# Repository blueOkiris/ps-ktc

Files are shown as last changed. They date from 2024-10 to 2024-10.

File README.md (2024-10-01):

# Polymath Studio Keyboard/Trackball Combo

NOTE: Project still in development!!!!

## Description

A keyboard and trackball in one, for efficient computer usage.

Like the [PS-OHK](https://github.com/blueOkiris/ps-ohk/), the PS-KTC attempts to provide an efficiently laid out keyboard which doesn't require moving your hands back and forth from the mouse.

Unlike the PS-OHK, it accomplishes this while allowing for typing quickly via using both hands. This is done by placing a trackball in the middle of the keyboard!

## Layout

Like the PS-OHK, the PS-KTC uses a custom keyboard layout designed around placing commonly used characters right on the home row followed by similar sounds being near each other. It also aims to be roughly a 100% keyboard, although a few shortcuts are taken.

Layout:

```
F1  F2  F3  F4  F5  F6                      F7  F8  F9  F10 F11 F12

                Hm  End                     PgU PgD

            3#                                      8*
        2@                                              9(
            F   4%                              7&  L
        D                                               U
Esc 1!      I   K   5%                      6^  P   R       0)
        T                                               O
Tab C       V   A   Y   LClk           RClk H   E   J       M
        X                                               W
Sft S       [{  G   ,<  Scrl                .>  B   ]}      N   `~
        ;:                Whl                          '"
CLk Z       \|  Ins BSp Del               -----     /?      Q
                                         /Track\
    =+  Up      Ctl Sp  Win             | Ball  |           -_   
                                         \     /    
    Lft Dwn Rt  Alt Ret Cmp               -----     
```

Where the home row is S, T, I, A, Space, Trackball, E, R, O, N

There are 82 keys here. Why not 100? Well, there are few reasons:

1. Due to the every key being available and close to a finger in this arrangement, there is no need for the 10 num-pad digits nor the Num Lock nor the num-pad duplicates of /, \*, -, +, Return, and \./Delete. That's 100 - 10 - 7 = 83
2. No Print Screen, Scroll Lock, or Pause because, let's be real, the vast majority of people, myself included, do not need these keys. Maybe Print Screen, but Super + Shift + S is a great key combo for screenshot, so Print Screen is not needed. That's 83 - 3 = 80 keys
3. Mouse clicks as keys. 82 (middle click = left + right)

## Cost

If you go with the recommended JLCPCB, Tindie, and Amazon links, the cost is roughly broken down like so

| Part | Cost (w/ shipping) |
|:---:|:---:|
| PCBs | $101.01 |
| Motion Sensor | $39.98 |
| Rotary Encoder  + Wires | $44.20 |
| Total | $185.19 |

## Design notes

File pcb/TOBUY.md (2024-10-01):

# Ordering

## PS-KTC PCBs

### Usb MCU

To build the USB/MCU board, you'll want to use the BOM/CPL in usb-mcu/ on JLCPCB.

### Keys

To build the IO-Expander board for connecting keys too, same as usb-mcu, but use the files in the keys/ folder

### Key(s)

You'll also need 82 of the key/ PCB. No assembly required.

## Other Things to Buy

### Motion Sensor

For the mouse motion sensing, grab a PMW3389 Motion Sensor like [this one](https://www.tindie.com/products/citizenjoe/pmw3389-motion-sensor/)

### Scroll Wheel

For the scroll wheel, grab [this rotary encoder](https://www.amazon.com/Cylewet-Encoder-Digital-Potentiometer-Arduino/dp/B07DM2YMT4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)

### Wires

You'll need a bunch of female to female jumper wires. Like 100 long ones and 100 short ones.

- [40x Long](https://www.amazon.com/Solderless-Multicolored-Electronic-Breadboard-Protoboard/dp/B09FP74HVH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)
- [40x Short](https://www.amazon.com/Solderless-Multicolored-Electronic-Breadboard-Protoboard/dp/B09FPL5QV8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)

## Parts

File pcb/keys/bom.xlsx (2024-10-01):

Comment | Designator | Footprint | Part #
PCA9505DGGY | IC_IOEXP2,IC_IOEXP1 | SOP50 P810X120-56N | C2669685

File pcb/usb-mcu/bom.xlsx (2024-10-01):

Comment | Designator | Footprint | Part #
CH552G | IC_MCU1 | SOP-16 | C111292
10k Ohm | R_I2C2,R_I2C1,R_PROG1 | 0603
100nF | C2,C1 | 0603
5.1k Ohm | R_CC2,R_CC1 | 0603
USB-C Con | J_USB1 | USB-C 16P | C2894898
6mm Push Button | SW_PROG1 |  | C255812

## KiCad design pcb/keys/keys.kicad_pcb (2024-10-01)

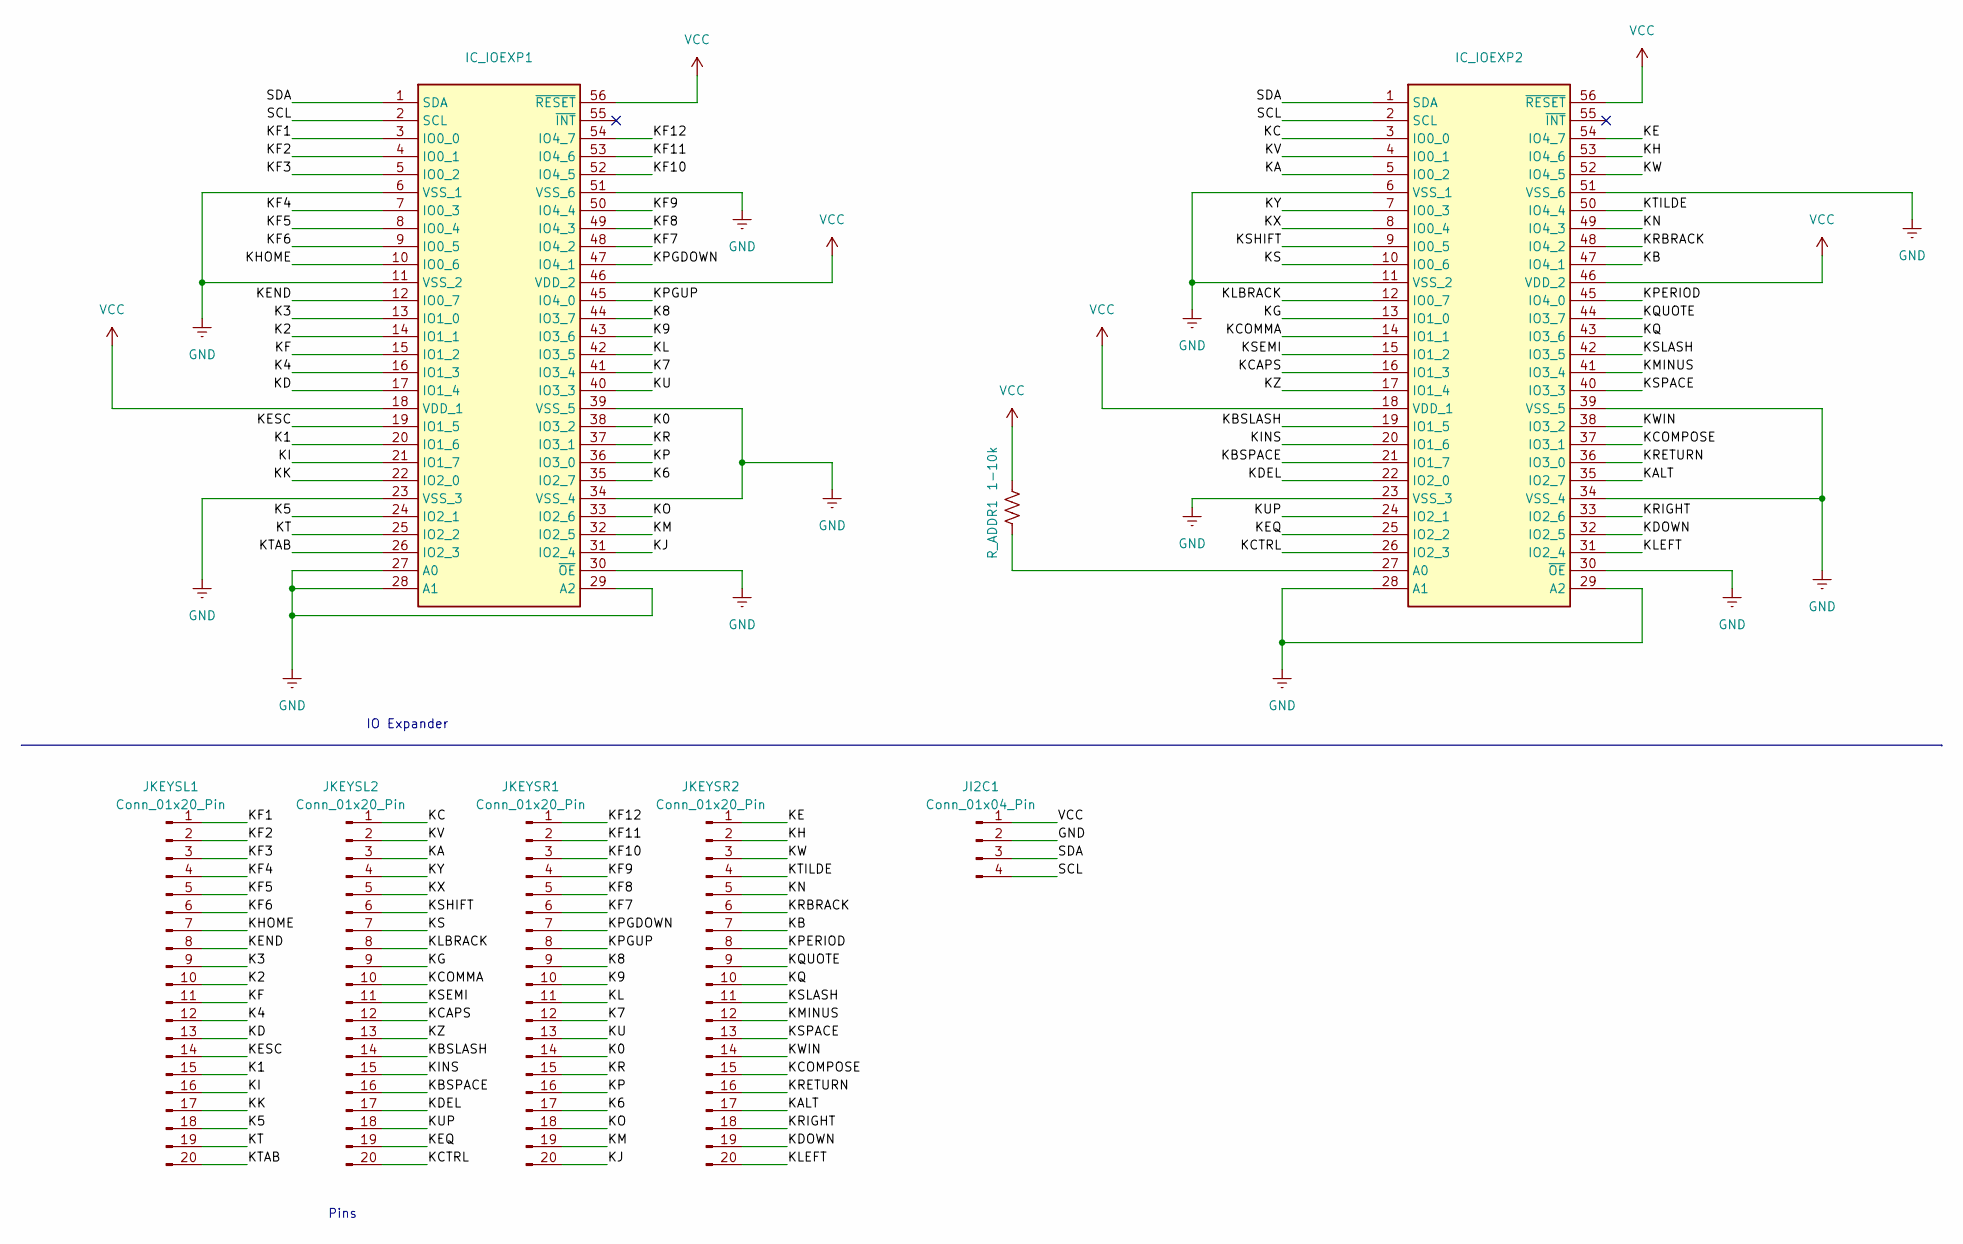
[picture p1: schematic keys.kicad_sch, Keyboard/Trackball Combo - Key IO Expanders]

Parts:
IC_IOEXP1, IC_IOEXP2: SOP50P810X120-56N; Mouser Part Number 771-PCA9505DGGY
JI2C1: Conn_01x04_Pin; PinHeader_1x04_P2.54mm_Vertical
JKEYSL1, JKEYSL2: Conn_01x20_Pin; PinHeader_1x20_P2.54mm_Vertical
JKEYSR1, JKEYSR2: Conn_01x20_Pin; PinHeader_1x20_P2.54mm_Vertical
R_ADDR1: 1-10k; R_0603_1608Metric

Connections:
/K0: IC_IOEXP1.38 (IO3_2), JKEYSR1.14
/K1: IC_IOEXP1.20 (IO1_6), JKEYSL1.15
/K2: IC_IOEXP1.14 (IO1_1), JKEYSL1.10
/K3: IC_IOEXP1.13 (IO1_0), JKEYSL1.9
/K4: IC_IOEXP1.16 (IO1_3), JKEYSL1.12
/K5: IC_IOEXP1.24 (IO2_1), JKEYSL1.18
/K6: IC_IOEXP1.35 (IO2_7), JKEYSR1.17
/K7: IC_IOEXP1.41 (IO3_4), JKEYSR1.12
/K8: IC_IOEXP1.44 (IO3_7), JKEYSR1.9
/K9: IC_IOEXP1.43 (IO3_6), JKEYSR1.10
/KA: IC_IOEXP2.5 (IO0_2), JKEYSL2.3
/KALT: IC_IOEXP2.35 (IO2_7), JKEYSR2.17
/KB: IC_IOEXP2.47 (IO4_1), JKEYSR2.7
/KBSLASH: IC_IOEXP2.19 (IO1_5), JKEYSL2.14
/KBSPACE: IC_IOEXP2.21 (IO1_7), JKEYSL2.16
/KC: IC_IOEXP2.3 (IO0_0), JKEYSL2.1
/KCAPS: IC_IOEXP2.16 (IO1_3), JKEYSL2.12
/KCOMMA: IC_IOEXP2.14 (IO1_1), JKEYSL2.10
/KCOMPOSE: IC_IOEXP2.37 (IO3_1), JKEYSR2.15
/KCTRL: IC_IOEXP2.26 (IO2_3), JKEYSL2.20
/KD: IC_IOEXP1.17 (IO1_4), JKEYSL1.13
/KDEL: IC_IOEXP2.22 (IO2_0), JKEYSL2.17
/KDOWN: IC_IOEXP2.32 (IO2_5), JKEYSR2.19
/KE: IC_IOEXP2.54 (IO4_7), JKEYSR2.1
/KEND: IC_IOEXP1.12 (IO0_7), JKEYSL1.8
/KEQ: IC_IOEXP2.25 (IO2_2), JKEYSL2.19
/KESC: IC_IOEXP1.19 (IO1_5), JKEYSL1.14
/KF: IC_IOEXP1.15 (IO1_2), JKEYSL1.11
/KF1: IC_IOEXP1.3 (IO0_0), JKEYSL1.1
/KF2: IC_IOEXP1.4 (IO0_1), JKEYSL1.2
/KF3: IC_IOEXP1.5 (IO0_2), JKEYSL1.3
/KF4: IC_IOEXP1.7 (IO0_3), JKEYSL1.4
/KF5: IC_IOEXP1.8 (IO0_4), JKEYSL1.5
/KF6: IC_IOEXP1.9 (IO0_5), JKEYSL1.6
/KF7: IC_IOEXP1.48 (IO4_2), JKEYSR1.6
/KF8: IC_IOEXP1.49 (IO4_3), JKEYSR1.5
/KF9: IC_IOEXP1.50 (IO4_4), JKEYSR1.4
/KF10: IC_IOEXP1.52 (IO4_5), JKEYSR1.3
/KF11: IC_IOEXP1.53 (IO4_6), JKEYSR1.2
/KF12: IC_IOEXP1.54 (IO4_7), JKEYSR1.1
/KG: IC_IOEXP2.13 (IO1_0), JKEYSL2.9
/KH: IC_IOEXP2.53 (IO4_6), JKEYSR2.2
/KHOME: IC_IOEXP1.10 (IO0_6), JKEYSL1.7
/KI: IC_IOEXP1.21 (IO1_7), JKEYSL1.16
/KINS: IC_IOEXP2.20 (IO1_6), JKEYSL2.15
/KJ: IC_IOEXP1.31 (IO2_4), JKEYSR1.20
/KK: IC_IOEXP1.22 (IO2_0), JKEYSL1.17
/KL: IC_IOEXP1.42 (IO3_5), JKEYSR1.11
/KLBRACK: IC_IOEXP2.12 (IO0_7), JKEYSL2.8
/KLEFT: IC_IOEXP2.31 (IO2_4), JKEYSR2.20
/KM: IC_IOEXP1.32 (IO2_5), JKEYSR1.19
/KMINUS: IC_IOEXP2.41 (IO3_4), JKEYSR2.12
/KN: IC_IOEXP2.49 (IO4_3), JKEYSR2.5
/KO: IC_IOEXP1.33 (IO2_6), JKEYSR1.18
/KP: IC_IOEXP1.36 (IO3_0), JKEYSR1.16
/KPERIOD: IC_IOEXP2.45 (IO4_0), JKEYSR2.8
/KPGDOWN: IC_IOEXP1.47 (IO4_1), JKEYSR1.7
/KPGUP: IC_IOEXP1.45 (IO4_0), JKEYSR1.8
/KQ: IC_IOEXP2.43 (IO3_6), JKEYSR2.10
/KQUOTE: IC_IOEXP2.44 (IO3_7), JKEYSR2.9
/KR: IC_IOEXP1.37 (IO3_1), JKEYSR1.15
/KRBRACK: IC_IOEXP2.48 (IO4_2), JKEYSR2.6
/KRETURN: IC_IOEXP2.36 (IO3_0), JKEYSR2.16
/KRIGHT: IC_IOEXP2.33 (IO2_6), JKEYSR2.18
/KS: IC_IOEXP2.10 (IO0_6), JKEYSL2.7
/KSEMI: IC_IOEXP2.15 (IO1_2), JKEYSL2.11
/KSHIFT: IC_IOEXP2.9 (IO0_5), JKEYSL2.6
/KSLASH: IC_IOEXP2.42 (IO3_5), JKEYSR2.11
/KSPACE: IC_IOEXP2.40 (IO3_3), JKEYSR2.13
/KT: IC_IOEXP1.25 (IO2_2), JKEYSL1.19
/KTAB: IC_IOEXP1.26 (IO2_3), JKEYSL1.20
/KTILDE: IC_IOEXP2.50 (IO4_4), JKEYSR2.4
/KU: IC_IOEXP1.40 (IO3_3), JKEYSR1.13
/KUP: IC_IOEXP2.24 (IO2_1), JKEYSL2.18
/KV: IC_IOEXP2.4 (IO0_1), JKEYSL2.2
/KW: IC_IOEXP2.52 (IO4_5), JKEYSR2.3
/KWIN: IC_IOEXP2.38 (IO3_2), JKEYSR2.14
/KX: IC_IOEXP2.8 (IO0_4), JKEYSL2.5
/KY: IC_IOEXP2.7 (IO0_3), JKEYSL2.4
/KZ: IC_IOEXP2.17 (IO1_4), JKEYSL2.13
/SCL: IC_IOEXP1.2 (SCL), IC_IOEXP2.2 (SCL), JI2C1.4
/SDA: IC_IOEXP1.1 (SDA), IC_IOEXP2.1 (SDA), JI2C1.3
GND: IC_IOEXP1.6 (VSS_1), IC_IOEXP1.11 (VSS_2), IC_IOEXP1.23 (VSS_3), IC_IOEXP1.27 (A0), IC_IOEXP1.28 (A1), IC_IOEXP1.29 (A2), IC_IOEXP1.30 (~OE), IC_IOEXP1.34 (VSS_4), IC_IOEXP1.39 (VSS_5), IC_IOEXP1.51 (VSS_6), IC_IOEXP2.6 (VSS_1), IC_IOEXP2.11 (VSS_2), IC_IOEXP2.23 (VSS_3), IC_IOEXP2.28 (A1), IC_IOEXP2.29 (A2), IC_IOEXP2.30 (~OE), IC_IOEXP2.34 (VSS_4), IC_IOEXP2.39 (VSS_5), IC_IOEXP2.51 (VSS_6), JI2C1.2
VCC: IC_IOEXP1.18 (VDD_1), IC_IOEXP1.46 (VDD_2), IC_IOEXP1.56 (~RESET), IC_IOEXP2.18 (VDD_1), IC_IOEXP2.46 (VDD_2), IC_IOEXP2.56 (~RESET), JI2C1.1, R_ADDR1.1

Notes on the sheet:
IO Expander
Pins

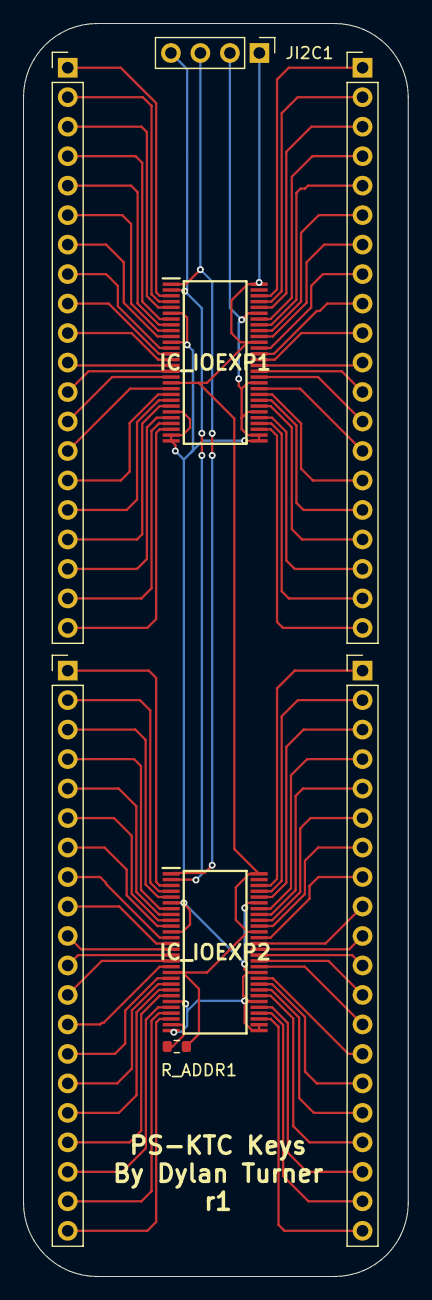
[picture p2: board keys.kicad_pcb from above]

Board: 2 copper layers, 33.1 x 107.9 mm, 8 parts (0 on the bottom side), 84 nets.

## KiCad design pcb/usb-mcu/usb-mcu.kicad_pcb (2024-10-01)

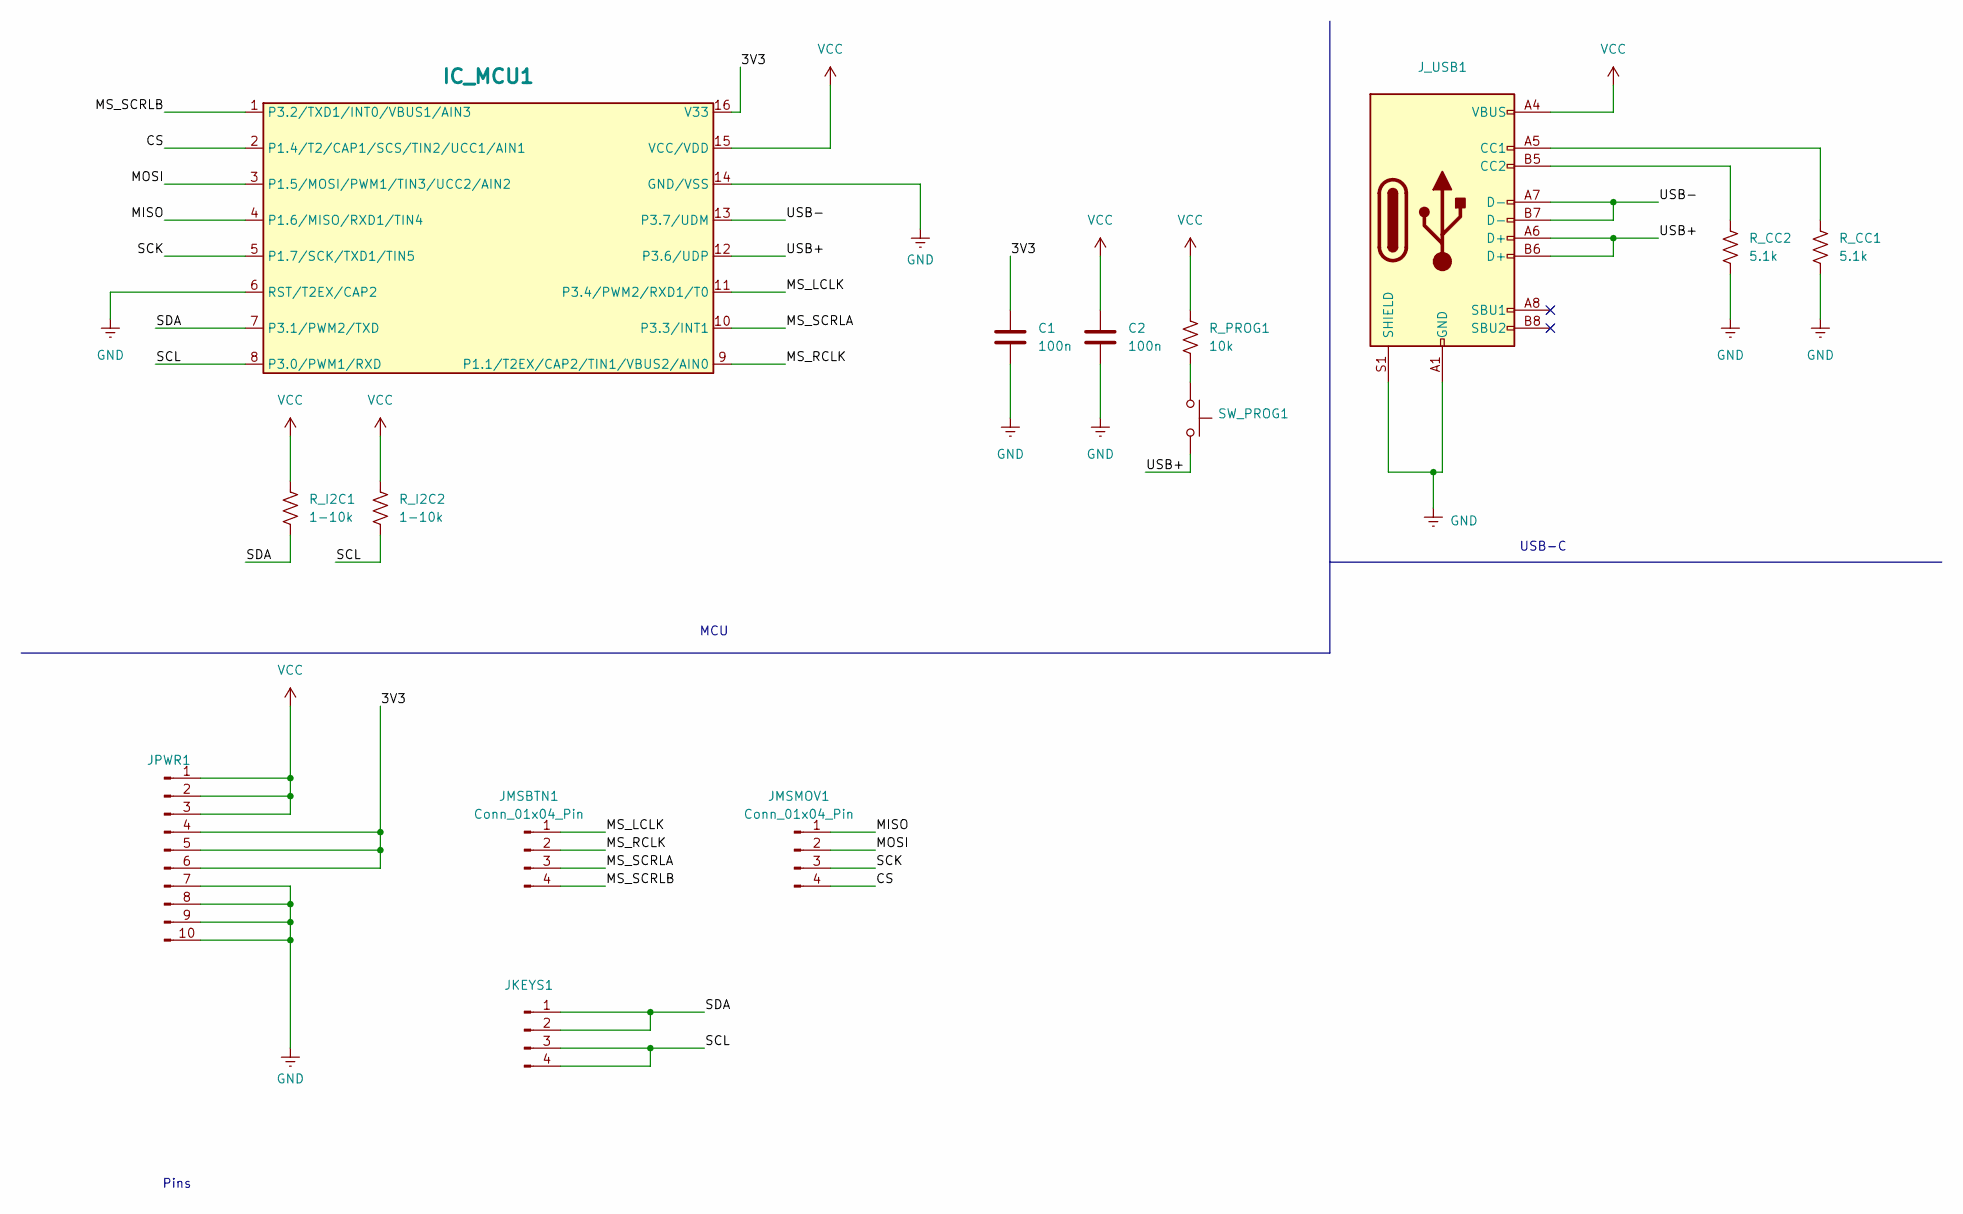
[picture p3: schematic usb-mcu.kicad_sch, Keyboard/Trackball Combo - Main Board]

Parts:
C1, C2: 100n; C_0603_1608Metric
IC_MCU1: SOIC-16_3.9x9.9mm_Pitch1.27mm
JKEYS1: PinHeader_1x04_P2.54mm_Vertical
JMSBTN1: Conn_01x04_Pin; PinHeader_1x04_P2.54mm_Vertical
JMSMOV1: Conn_01x04_Pin; PinHeader_1x04_P2.54mm_Vertical
JPWR1: PinHeader_1x10_P2.54mm_Vertical
J_USB1: USB_C_Receptacle_HCTL_HC-TYPE-C-16P-01A
R_CC1, R_CC2: 5.1k; R_0603_1608Metric
R_I2C1, R_I2C2: 1-10k; R_0603_1608Metric
R_PROG1: 10k; R_0603_1608Metric
SW_PROG1: SW_Push_1P1T_NO_6x6mm_H9.5mm

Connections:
/3V3: C1.1, IC_MCU1.16 (V33), JPWR1.4, JPWR1.5, JPWR1.6
/CS: IC_MCU1.2 (P1.4/T2/CAP1/SCS/TIN2/UCC1/AIN1), JMSMOV1.4
/MISO: IC_MCU1.4 (P1.6/MISO/RXD1/TIN4), JMSMOV1.1
/MOSI: IC_MCU1.3 (P1.5/MOSI/PWM1/TIN3/UCC2/AIN2), JMSMOV1.2
/MS_LCLK: IC_MCU1.11 (P3.4/PWM2/RXD1/T0), JMSBTN1.1
/MS_RCLK: IC_MCU1.9 (P1.1/T2EX/CAP2/TIN1/VBUS2/AIN0), JMSBTN1.2
/MS_SCRLA: IC_MCU1.10 (P3.3/INT1), JMSBTN1.3
/MS_SCRLB: IC_MCU1.1 (P3.2/TXD1/INT0/VBUS1/AIN3), JMSBTN1.4
/SCK: IC_MCU1.5 (P1.7/SCK/TXD1/TIN5), JMSMOV1.3
/SCL: IC_MCU1.8 (P3.0/PWM1/RXD), JKEYS1.3, JKEYS1.4, R_I2C2.2
/SDA: IC_MCU1.7 (P3.1/PWM2/TXD), JKEYS1.1, JKEYS1.2, R_I2C1.2
/USB+: IC_MCU1.12 (P3.6/UDP), J_USB1.A6 (D+), J_USB1.B6 (D+), SW_PROG1.2
/USB-: IC_MCU1.13 (P3.7/UDM), J_USB1.A7 (D-), J_USB1.B7 (D-)
GND: C1.2, C2.2, IC_MCU1.6 (RST/T2EX/CAP2), IC_MCU1.14 (GND/VSS), JPWR1.7, JPWR1.8, JPWR1.9, JPWR1.10, J_USB1.A1 (GND), J_USB1.A12 (GND), J_USB1.B1 (GND), J_USB1.B12 (GND), J_USB1.S1 (SHIELD), R_CC1.2, R_CC2.2
unnamed: J_USB1.A5 (CC1), R_CC1.1
unnamed: J_USB1.B5 (CC2), R_CC2.1
unnamed: R_PROG1.2, SW_PROG1.1
VCC: C2.1, IC_MCU1.15 (VCC/VDD), JPWR1.1, JPWR1.2, JPWR1.3, J_USB1.A4 (VBUS), J_USB1.A9 (VBUS), J_USB1.B4 (VBUS), J_USB1.B9 (VBUS), R_I2C1.1, R_I2C2.1, R_PROG1.1

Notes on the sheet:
USB-C
Pins
MCU

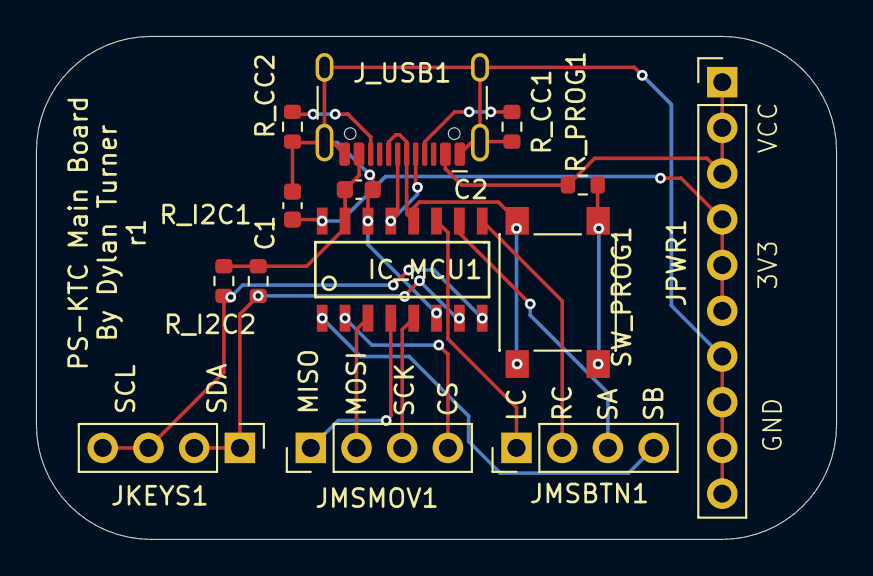
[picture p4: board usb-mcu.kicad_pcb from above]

Board: 2 copper layers, 44.5 x 27.9 mm, 14 parts (0 on the bottom side), 18 nets.
